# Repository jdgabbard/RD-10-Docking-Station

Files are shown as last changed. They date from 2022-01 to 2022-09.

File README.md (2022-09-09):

# RD-10-Docking-Station
A DIY Docking Station for the Casio MX-10 / MX-15 MSX computers

***REV 2 Board Added to Repository***

***See Build Notes file for special instructions!***

Designed to replace or substitute the KB-10 or KB-15 docking station. Future releases may expand this design. For now, consider it a way to have more than one catridge in your MX-10 or MX-15 at a time.  ***For details, see below.***

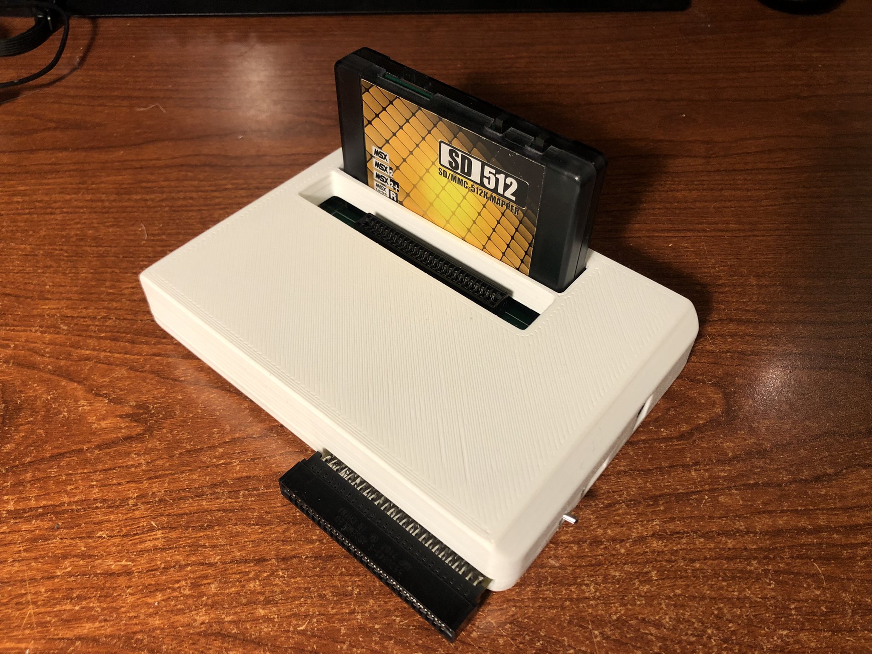
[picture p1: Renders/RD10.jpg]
RD10


Features include:<br><br>
-The ability to directly power the Mx-10 / MX-15 / MX-101 computer from the RD-10 Docking Station.<br>
-Integrated Power Switch for turning on the MX-10.<br>
-Experimental Audio Input Jack (2.5mm) for injecting music into the MSX audio amplifier.<br>
-External Power Connector, allowing powering of Floppy Drives directly from the Docking Station.<br>
-Two Primary Slots<br>
-Construction consisting of off the shelf TTL logic, and current production PLD (ATF22V10).<br>
-Implements +12v/-12v rails, so Audio Cartridges work correctly (MX-10 did not do this on it's one cartridge slot).<br><br>

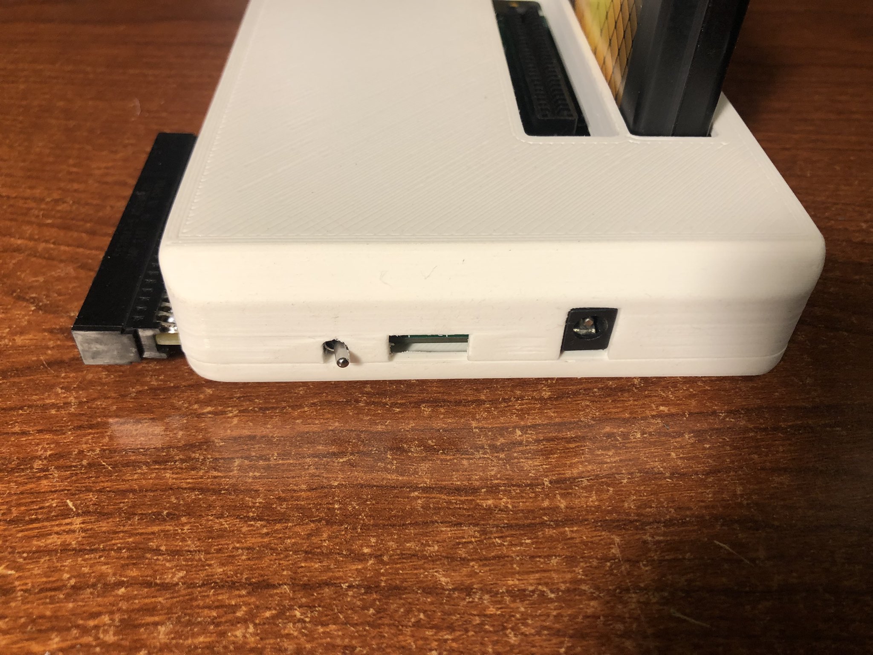
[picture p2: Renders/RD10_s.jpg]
Side

Board

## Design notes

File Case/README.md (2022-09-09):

# RD-10 Printable Enclosure

There are two sets of STL files, a Fusion 360 Archive, and a copy in STEP format.<br>

The STLs are grouped into two categories:  The first being the original exports in millimeters.  The second (resized), which has been resized to 10% of the orignal size.  The second set is for applications where importation assumes the design to be in imperial sizes, and creates a giant version.<br><br>

The Fusion 360 Archive can be used to modify the original design.  You're welcome...<br>

The STEP format can be used to import into other CAD software.  You're welcome...<br>

Build Note: HRA reports M3.5 x 12mm counter sunk screws are a perfect fit.<br>

If you have any issues with these files, please let me know.<br>

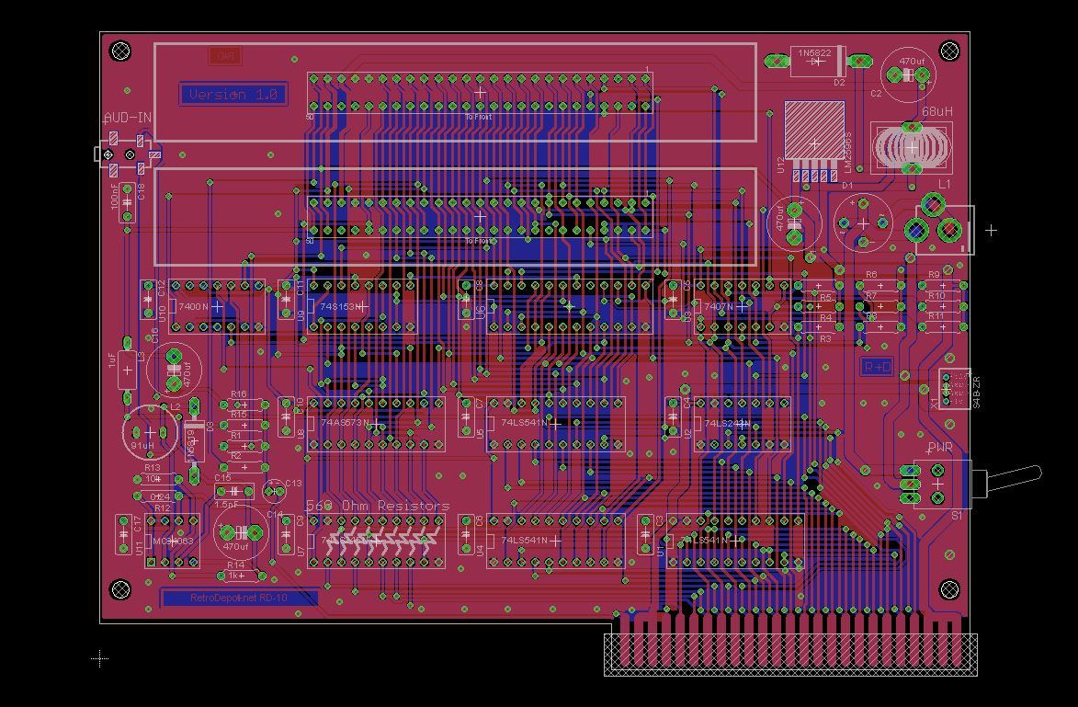
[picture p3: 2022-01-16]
Renders/Board.JPG

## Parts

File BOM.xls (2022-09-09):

Part | Value | Amount | Digikey | Part# | Mouser | Part#
C1,C2,C14,C16 | 470uf | 4 | 732-8743-1-ND | 710-860010575013
C3,C4,C5,C6,C7,C8,C9,C10,C11,C12,C17,C18 | 100nF | 12 | BC1101CT-ND | 594-K104K15X7RF5TH5
C13 | 220uF | 1 | 1189-2237-ND | 232-25YXJ100M5X11
C15 | 1.5nF | 1 | C321C152K3G5TA-ND | 80-C321C152K3G5TA
CONN1,CONN2,CONN3 | Card | Edge | Conn | 3 | A144214-ND | 571-1-5530843-6
D1 | 2W10 | 1 | 2W10G-E4/51 | 625-2W10G-E4
D2 | 1N5822 | 1 | 497-14742-2-ND | 511-1N5822-TR
D3 | 1N5819 | 1 | 497-6610-1-ND | 511-1N581
JP1 | DC | Jack | 1 | CP-002A-ND | 490-PJ-002A
JP2 | Audio | Conn | 1 | 137-MDSMT2BRATRXCT-ND | (unconfirmed) | 502-MDSMT2BRATRX | (unconfirmed)
L1 | 68uH | 1 | 308-2335-ND | (unconfirmed) | 851-RCH8011NP-680L | (unconfirmed)
L2 | 91uH | (100uH) | 1 | 399-20012-ND | (unconfirmed) | 80-SBCP-47HY101B | (unconfirmed)
L3 | 1uF | 1 | 495-5547-2-ND | (unconfirmed) | 871-B78108S1102K | (unconfirmed)
R1,R2,R15,R16 | 330R | 4 | MFR-25FBF52-330R-ND | 603-MFR-25FBF52-330R
R3,R4,R5,R6,R7,R8,R9,R10,R11 | 4.7k | 9 | 4.7KQBK-ND | 603-CFR-25JB-52-4K7
R12 | 0.24R | 1 | A138235CT-ND | 279-RR01JR24TB
R13 | 10k | 1 | 10KQBK-ND | 603-CFR-25JB-52-10K
R14 | 1k | 1 | 1.0KQBK-ND | 603-CFR-25JB-1K0
S1 | Power | Switch | 1 | EG5420-ND | 612-200MSP1T3B4M6RE
U1,U4,U5 | 74F541N | 3 | 296-3594-5-ND | 595-SN74F541N
U2 | 74ALS243N | (HCT) | 1 | 296-2145-5-ND | 595-CD74HCT243E
U3 | 74LS07N | 1 | 296-14878-5-ND | 595-SN74LS07N
U6 | 22V10 | 1 | 2156-ATF22V10CQ-15PC-AT-ND | 556-AF22V10C7PX
U7 | -See | Note- | 8 | CF14JT560RCT-ND | 603-CFR-25JB-52-560R
U8 | 74LS573N | (HCT) | 1 | 296-2128-5-ND | 595-CD74HCT573E
U9 | 74F153N | 1 | 296-3555-5-ND | 595-SN74F153N
U10 | 74F00N | 1 | 296-3539-5-ND | 595-SN74F00N
U11 | MC34063 | 1 | 497-4280-5-ND | 511-MC34063ECN
U12 | LM2596S | 1 | LM2596S-5.0/NOPB-ND | 926-LM2596S-5.0/NOPB
X1 | Floppy | Power | Conn | 1 | A144577-ND | 571-3-641207-4 | Not | currently | used, | wrong | footprint.
Notes:
U7 | should be fitted with 560ohm resistors as noted on PCB
R13 in Rev2 | should be 10k potentiometer

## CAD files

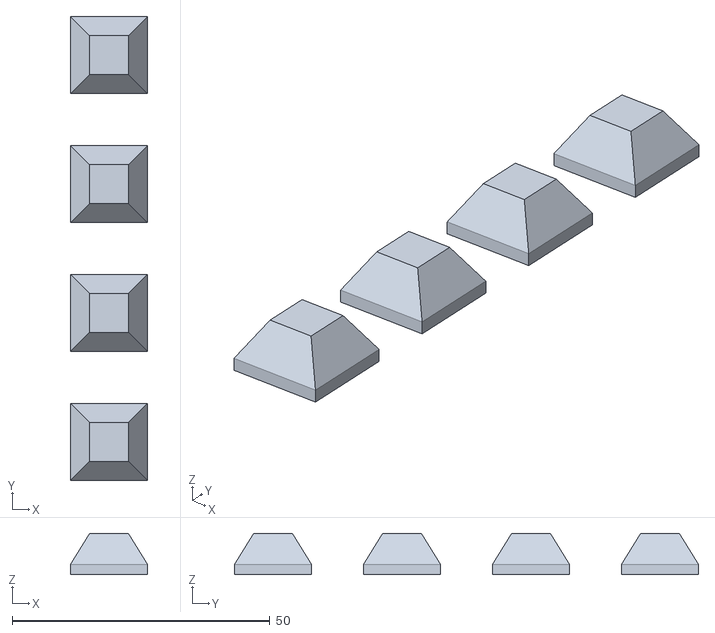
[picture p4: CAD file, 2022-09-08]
Case/Feet_resized.stl
14.9 x 89.9 x 8.00

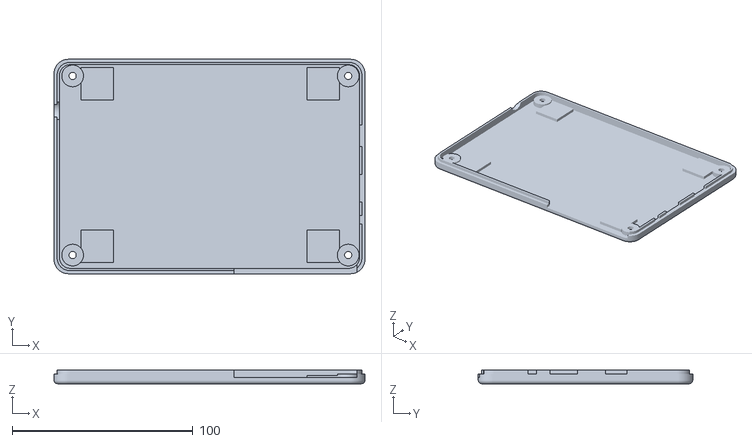
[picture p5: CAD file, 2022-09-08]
Case/Base_resized.stl
172.0 x 118.6 x 7.50

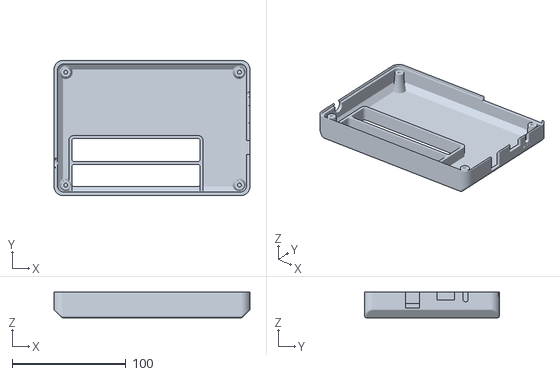
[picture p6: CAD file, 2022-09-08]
Case/Top_resized.stl
172.0 x 118.7 x 22.5

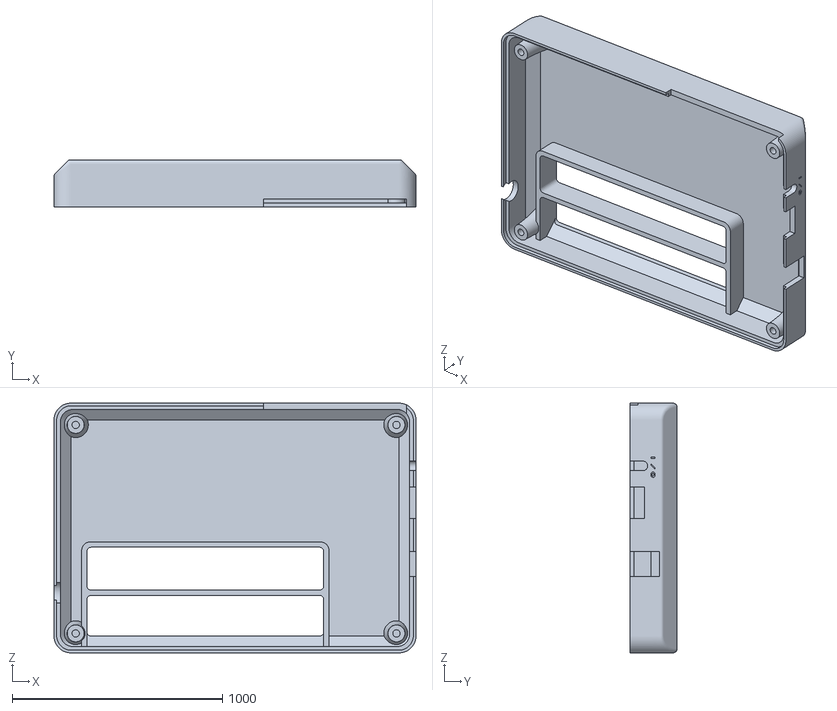
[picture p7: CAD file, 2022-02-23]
Case/Top.stl
1720.0 x 225.0 x 1186.5

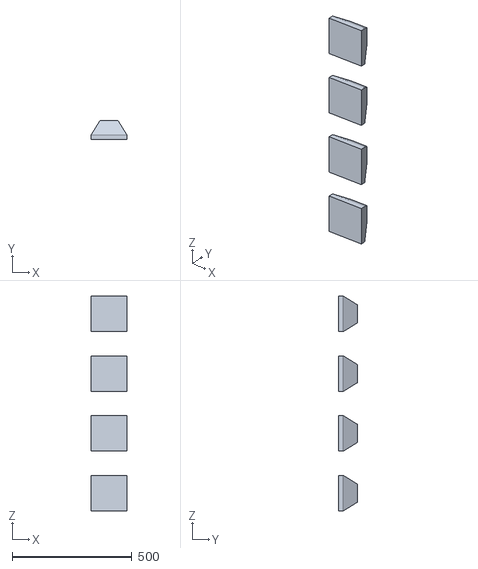
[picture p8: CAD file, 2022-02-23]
Case/Feet.stl
149.3 x 80.0 x 899.3

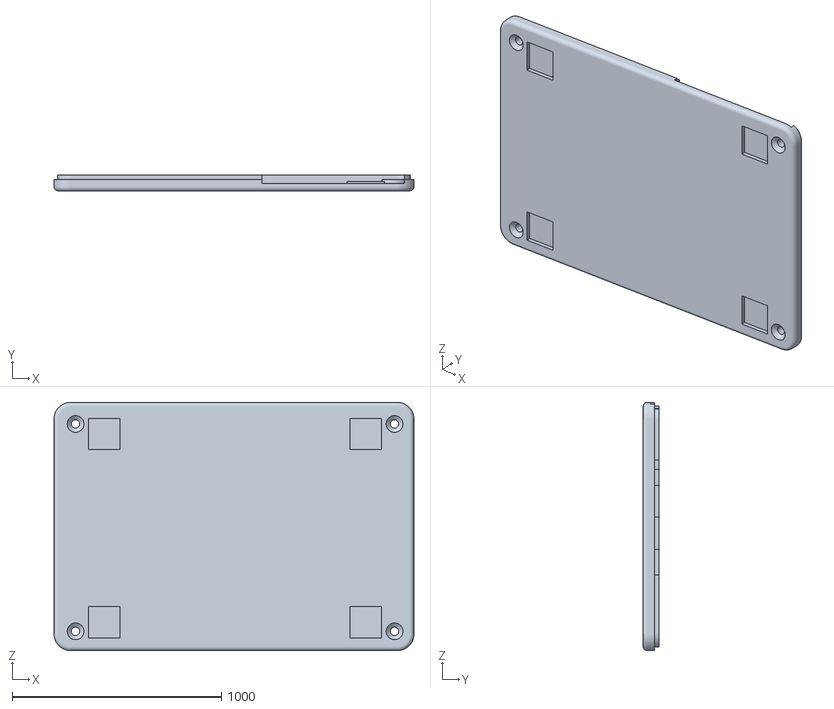
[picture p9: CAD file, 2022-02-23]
Case/Base.stl
1720.0 x 75.0 x 1186.5

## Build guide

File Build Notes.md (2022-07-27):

# Build Notes

***I would suggest fitting U6 and U7 with Sockets.***  U6 is for the 22V10 PLD, and should be socketed so updated JEDECs can be programmed.  I suggest socketing U7 to allow switching between a Bus Transceiver and Resistor.  Once the cause of the Bus Transceiver's incorrect operation is determined, a modified JEDEC, BOM or Board design will be released so that a Transceiver can be used.

***Until then use resistors in place of U7!***

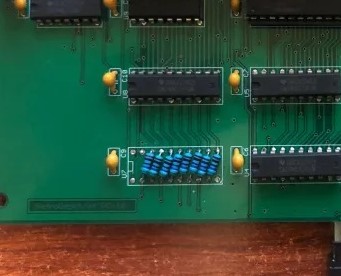
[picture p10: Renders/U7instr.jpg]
U7


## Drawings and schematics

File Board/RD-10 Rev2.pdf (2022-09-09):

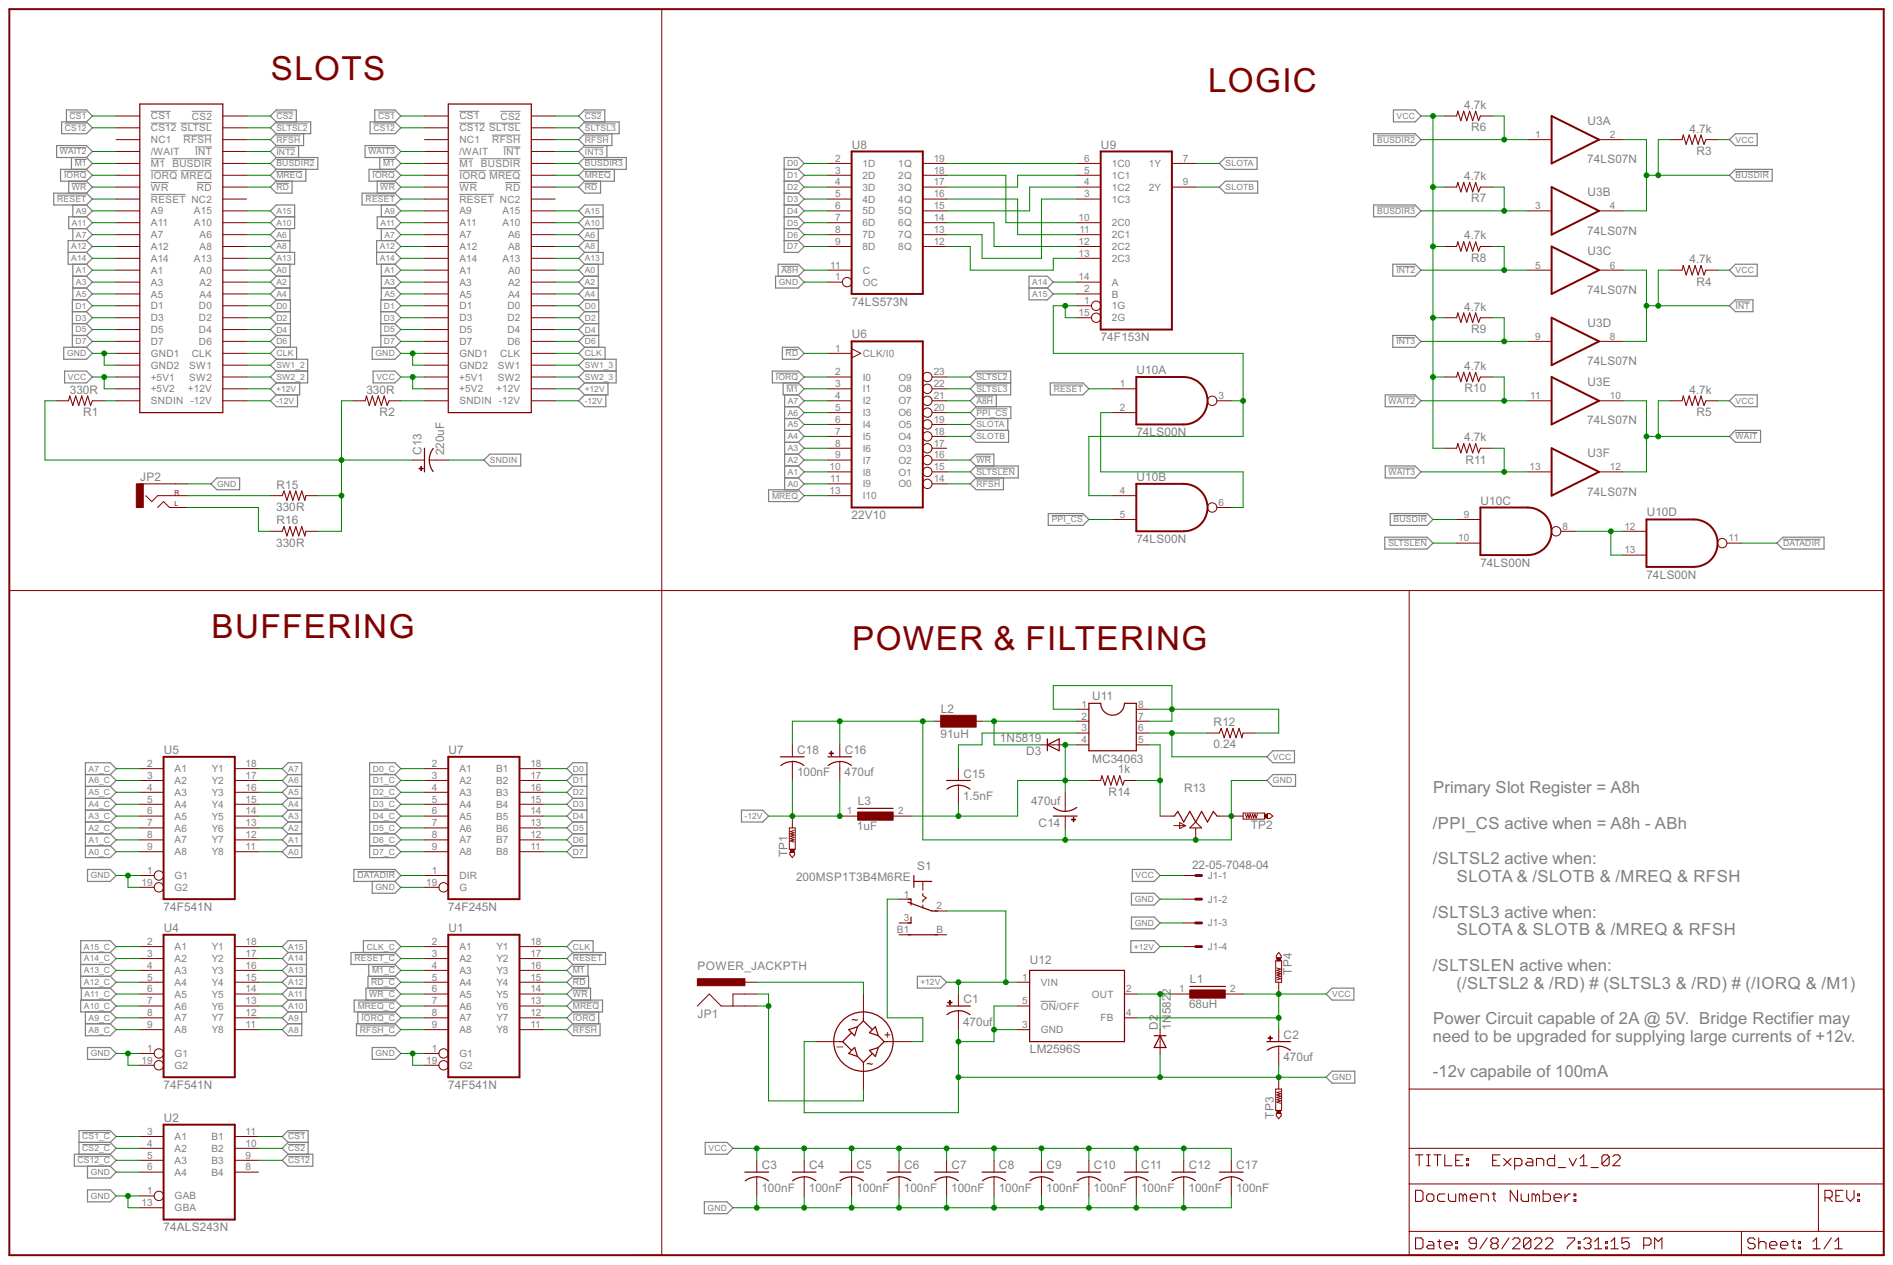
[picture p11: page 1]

GND | 2 A15

/SLTSL2 active when: SLOTA & /SLOTB & /MREQ & RFSH

/SLTSL3 active when: SLOTA & SLOTB & /MREQ & RFSH

/SLTSLEN active when: (/SLTSL2 & /RD) # (SLTSL3 & /RD) # (/IORQ & /M1)

Power Circuit capable of 2A @ 5V. Bridge Rectifier may need to be upgraded for supplying large currents of +12v. -12v capabile of 100mA

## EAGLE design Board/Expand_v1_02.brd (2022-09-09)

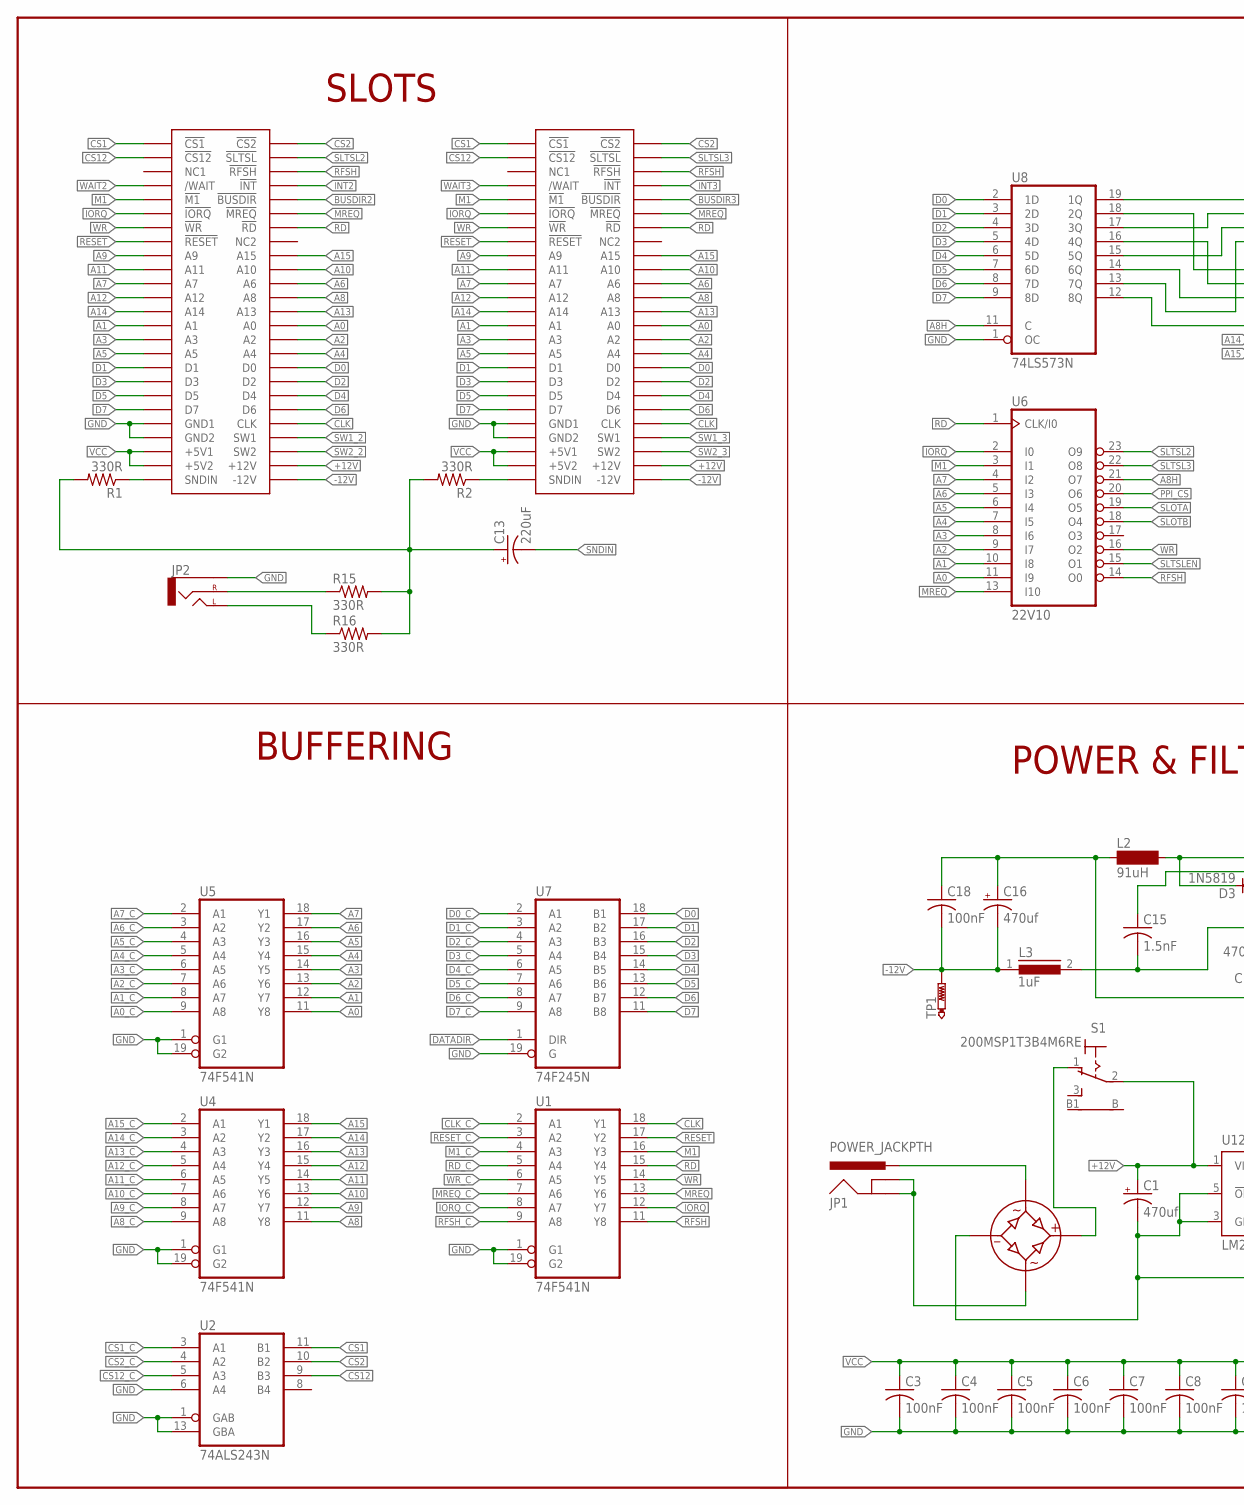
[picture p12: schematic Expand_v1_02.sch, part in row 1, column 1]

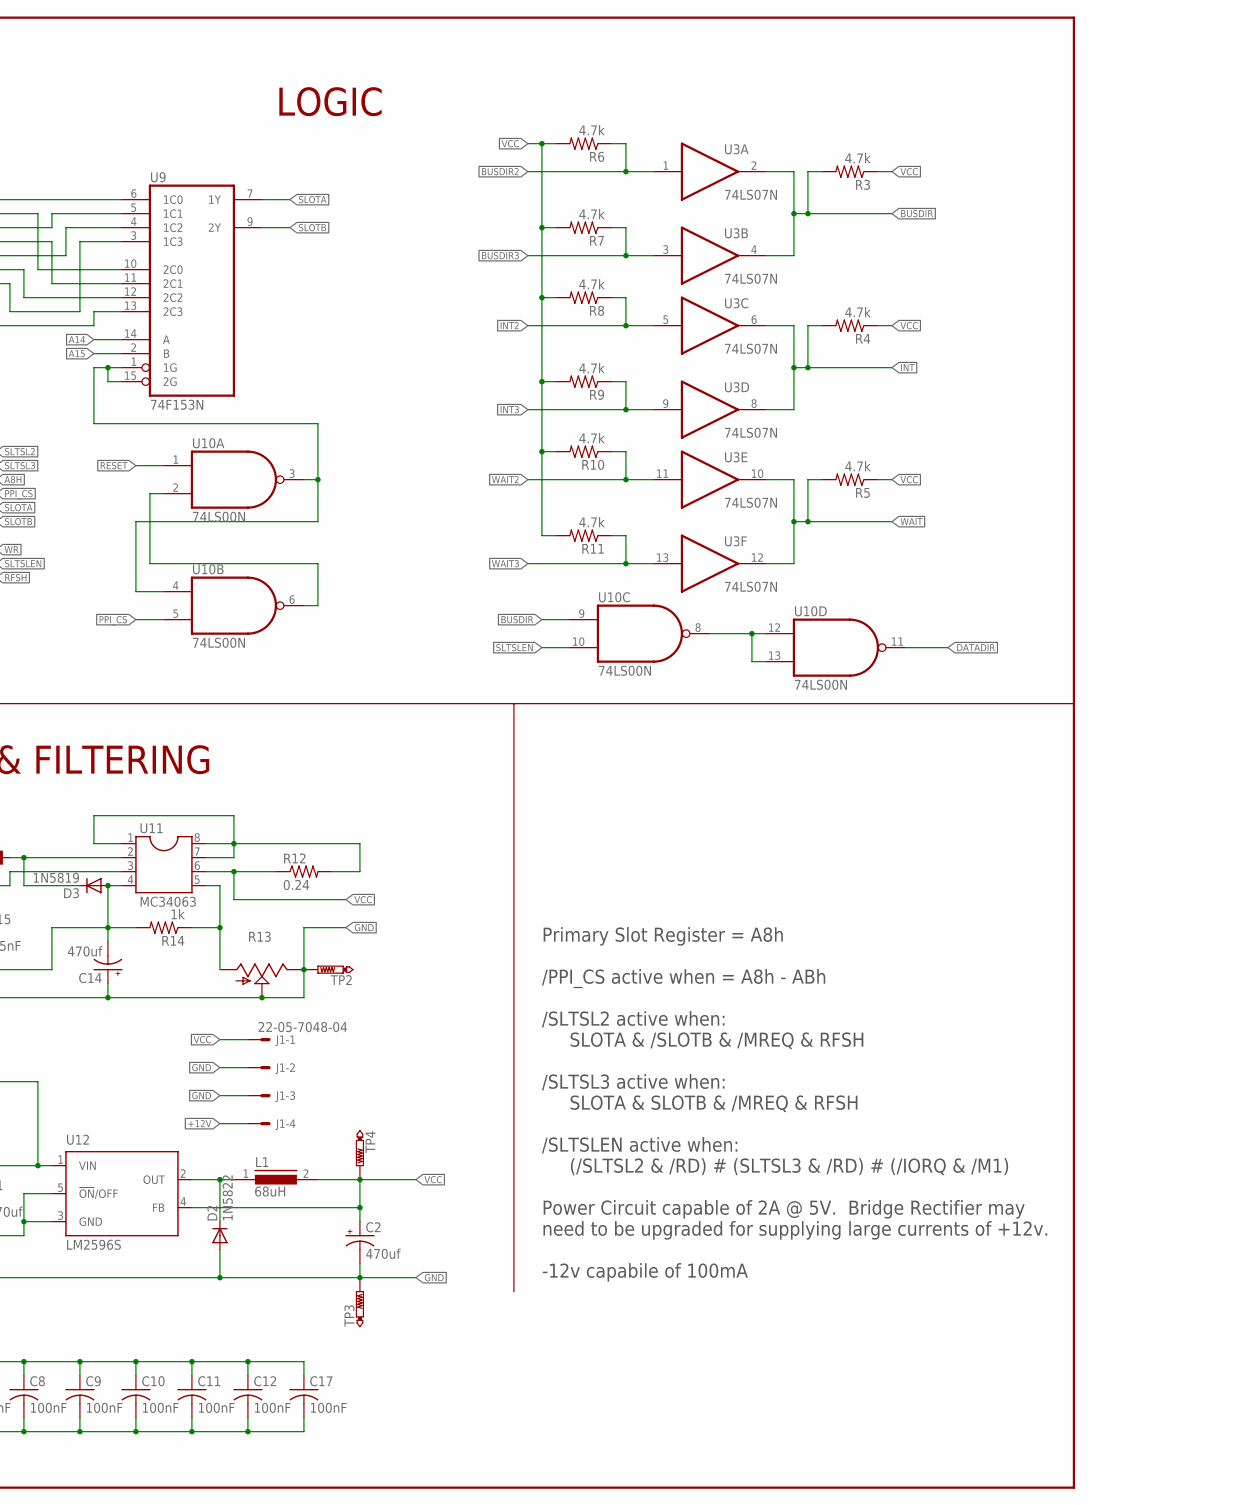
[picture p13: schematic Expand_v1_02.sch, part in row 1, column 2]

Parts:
C1, C2, C14, C16: 470uf; E5-10,5
C3, C4, C5, C6, C7, C8, C9, C10, C11, C12, C17, C18: 100nF; C050-030X075
C13: 220uF; E2-4
C15: 1.5nF; C050-030X075
CONN2, CONN3: MSX_CART_SLOT; CART_SLOT
D1: 2W10
D2: 1N5822; DO201-15
D3: 1N5819; DO15-12
J1: 22-05-7048-04; 7395-04
JP1: POWER_JACKPTH; POWER_JACK_PTH
JP2: AUDIO-JACK1:1; STEREOJACK2.5MM
L1: 68uH; A26GFC
L2: 91uH; BS11
L3: 1uF; MCC10
R1, R2, R15, R16: 330R; 0207/7
R3, R4, R5, R6, R7, R8, R9, R10, R11: 4.7k; 0207/7
R12: 0.24; 0207/10
R13: TRIM_US-RJ9W; RJ9W
R14: 1k; 0207/7
S1: 200MSP1T3B4M6RE; 9070-1W
TP1, TP2, TP3, TP4: PTR1B2,54; B2,54
U1, U4, U5: 74F541N; DIL20
U2: 74ALS243N; DIL14
U3: 74LS07N; DIL14
U6: 22V10; DIL24-3
U7: 74F245N; DIL20
U8: 74LS573N; DIL20
U9: 74F153N; DIL16
U10: 74LS00N; DIL14
U11: MC34063; DIL08
U12: LM2596S; TO263-5

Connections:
!A8H: U6.21 (O7), U8.11 (C)
!BUSDIR: R3.2, U3.2 (O), U3.4 (O), U10.9 (I0)
!BUSDIR2: CONN2.P$10 (!BUSDIR), R6.1, U3.1 (I)
!BUSDIR3: CONN3.P$10 (!BUSDIR), R7.1, U3.3 (I)
!CS1: CONN2.P$1 (!CS1), CONN3.P$1 (!CS1), U2.11 (B1)
!CS1_C: U2.3 (A1)
!CS2: CONN2.P$2 (!CS2), CONN3.P$2 (!CS2), U2.10 (B2)
!CS2_C: U2.4 (A2)
!CS12: CONN2.P$3 (!CS12), CONN3.P$3 (!CS12), U2.9 (B3)
!CS12_C: U2.5 (A3)
!DATADIR: U7.1 (DIR), U10.11 (O)
!INT: R4.2, U3.6 (O), U3.8 (O)
!INT2: CONN2.P$8 (!INT), R8.1, U3.5 (I)
!INT3: CONN3.P$8 (!INT), R9.1, U3.9 (I)
!IORQ: CONN2.P$11 (!IORQ), CONN3.P$11 (!IORQ), U1.12 (Y7), U6.2 (I0)
!IORQ_C: U1.8 (A7)
!M1: CONN2.P$9 (!M1), CONN3.P$9 (!M1), U1.16 (Y3), U6.3 (I1)
!M1_C: U1.4 (A3)
!MREQ: CONN2.P$12 (!MREQ), CONN3.P$12 (!MREQ), U1.13 (Y6), U6.13 (I10)
!MREQ_C: U1.7 (A6)
!PPI_CS: U6.20 (O6), U10.5 (I1)
!RD: CONN2.P$14 (!RD), CONN3.P$14 (!RD), U1.15 (Y4), U6.1 (CLK/I0)
!RD_C: U1.5 (A4)
!RESET: CONN2.P$15 (!RESET), CONN3.P$15 (!RESET), U1.17 (Y2), U10.1 (I0)
!RESET_C: U1.3 (A2)
!RFSH: CONN2.P$6 (!RFSH), CONN3.P$6 (!RFSH), U1.11 (Y8), U6.14 (O0)
!RFSH_C: U1.9 (A8)
!SLTSL2: CONN2.P$4 (!SLTSL), U6.23 (O9)
!SLTSL3: CONN3.P$4 (!SLTSL), U6.22 (O8)
!SLTSLEN: U6.15 (O1), U10.10 (I1)
!WAIT: R5.2, U3.10 (O), U3.12 (O)
!WAIT2: CONN2.P$7 (/WAIT), R10.1, U3.11 (I)
!WAIT3: CONN3.P$7 (/WAIT), R11.1, U3.13 (I)
!WR: CONN2.P$13 (!WR), CONN3.P$13 (!WR), U1.14 (Y5), U6.16 (O2)
!WR_C: U1.6 (A5)
+12V: C1.+, CONN2.P$48 (+12V), CONN3.P$48 (+12V), J1.4, S1.2, U12.1 (VIN)
-12V: C16.-, C18.2, CONN2.P$50 (-12V), CONN3.P$50 (-12V), L3.1, TP1.TP
A0: CONN2.P$28 (A0), CONN3.P$28 (A0), U5.11 (Y8), U6.11 (I9)
A0_C: U5.9 (A8)
A1: CONN2.P$27 (A1), CONN3.P$27 (A1), U5.12 (Y7), U6.10 (I8)
A1_C: U5.8 (A7)
A2: CONN2.P$30 (A2), CONN3.P$30 (A2), U5.13 (Y6), U6.9 (I7)
A2_C: U5.7 (A6)
A3: CONN2.P$29 (A3), CONN3.P$29 (A3), U5.14 (Y5), U6.8 (I6)
A3_C: U5.6 (A5)
A4: CONN2.P$32 (A4), CONN3.P$32 (A4), U5.15 (Y4), U6.7 (I5)
A4_C: U5.5 (A4)
A5: CONN2.P$31 (A5), CONN3.P$31 (A5), U5.16 (Y3), U6.6 (I4)
A5_C: U5.4 (A3)
A6: CONN2.P$22 (A6), CONN3.P$22 (A6), U5.17 (Y2), U6.5 (I3)
A6_C: U5.3 (A2)
A7: CONN2.P$21 (A7), CONN3.P$21 (A7), U5.18 (Y1), U6.4 (I2)
A7_C: U5.2 (A1)
A8: CONN2.P$24 (A8), CONN3.P$24 (A8), U4.11 (Y8)
A8_C: U4.9 (A8)
A9: CONN2.P$17 (A9), CONN3.P$17 (A9), U4.12 (Y7)
A9_C: U4.8 (A7)
A10: CONN2.P$20 (A10), CONN3.P$20 (A10), U4.13 (Y6)
A10_C: U4.7 (A6)
A11: CONN2.P$19 (A11), CONN3.P$19 (A11), U4.14 (Y5)
A11_C: U4.6 (A5)
A12: CONN2.P$23 (A12), CONN3.P$23 (A12), U4.15 (Y4)
A12_C: U4.5 (A4)
A13: CONN2.P$26 (A13), CONN3.P$26 (A13), U4.16 (Y3)
A13_C: U4.4 (A3)
A14: CONN2.P$25 (A14), CONN3.P$25 (A14), U4.17 (Y2), U9.14 (A)
A14_C: U4.3 (A2)
A15: CONN2.P$18 (A15), CONN3.P$18 (A15), U4.18 (Y1), U9.2 (B)
A15_C: U4.2 (A1)
CLK: CONN2.P$42 (CLK), CONN3.P$42 (CLK), U1.18 (Y1)
CLK_C: U1.2 (A1)
D0: CONN2.P$34 (D0), CONN3.P$34 (D0), U7.18 (B1), U8.2 (1D)
D0_C: U7.2 (A1)
D1: CONN2.P$33 (D1), CONN3.P$33 (D1), U7.17 (B2), U8.3 (2D)
D1_C: U7.3 (A2)
D2: CONN2.P$36 (D2), CONN3.P$36 (D2), U7.16 (B3), U8.4 (3D)
D2_C: U7.4 (A3)
D3: CONN2.P$35 (D3), CONN3.P$35 (D3), U7.15 (B4), U8.5 (4D)
D3_C: U7.5 (A4)
D4: CONN2.P$38 (D4), CONN3.P$38 (D4), U7.14 (B5), U8.6 (5D)
D4_C: U7.6 (A5)
D5: CONN2.P$37 (D5), CONN3.P$37 (D5), U7.13 (B6), U8.7 (6D)
D5_C: U7.7 (A6)
D6: CONN2.P$40 (D6), CONN3.P$40 (D6), U7.12 (B7), U8.8 (7D)
D6_C: U7.8 (A7)
D7: CONN2.P$39 (D7), CONN3.P$39 (D7), U7.11 (B8), U8.9 (8D)
D7_C: U7.9 (A8)
GND: C1.-, C2.-, C3.2, C4.2, C5.2, C6.2, C7.2, C8.2, C9.2, C10.2, C11.2, C12.2, C14.+, C16.+, C17.2, C18.1, CONN2.P$41 (GND1), CONN2.P$43 (GND2), CONN3.P$41 (GND1), CONN3.P$43 (GND2), D1.P$4, D2.A, J1.2, J1.3, JP2.5 (SLEEVE), L2.1, R13.E, R13.S, TP2.TP, TP3.TP, U1.1 (G1), U1.10 (GND), U1.19 (G2), U2.1 (GAB), U2.6 (A4), U2.7 (GND), U2.13 (GBA), U3.7 (GND), U4.1 (G1), U4.10 (GND), U4.19 (G2), U5.1 (G1), U5.10 (GND), U5.19 (G2), U6.12 (GND), U7.10 (GND), U7.19 (G), U8.1 (OC), U8.10 (GND), U9.8 (GND), U10.7 (GND), U12.3 (GND), U12.5 (!ON!/OFF)
unnamed: CONN3.P$49 (SNDIN), R2.1
unnamed: CONN2.P$49 (SNDIN), R1.1
unnamed: U8.19 (1Q), U9.6 (1C0)
unnamed: C13.+, R1.2, R2.2, R15.2, R16.2
unnamed: U8.18 (2Q), U9.10 (2C0)
unnamed: U8.17 (3Q), U9.5 (1C1)
unnamed: U8.16 (4Q), U9.11 (2C1)
unnamed: U8.15 (5Q), U9.4 (1C2)
unnamed: U8.14 (6Q), U9.12 (2C2)
unnamed: U8.13 (7Q), U9.3 (1C3)
unnamed: U8.12 (8Q), U9.13 (2C3)
unnamed: U10.2 (I1), U10.6 (O)
unnamed: U9.1 (1G), U9.15 (2G), U10.3 (O), U10.4 (I0)
unnamed: U10.8 (O), U10.12 (I0), U10.13 (I1)
unnamed: D1.P$2, S1.1 (O)
unnamed: R12.2, U11.1, U11.7, U11.8
unnamed: JP2.4 (RIGHT), R15.1
unnamed: R13.A, R14.1, U11.5
unnamed: D1.P$1, JP1.PWR
unnamed: D1.P$3, JP1.GND, JP1.GNDBREAK
unnamed: C14.-, C15.2, D3.A, L3.2, R14.2, U11.4
unnamed: C15.1, U11.3
unnamed: D3.C, L2.2, U11.2
unnamed: JP2.1 (LEFT), R16.1
unnamed: D2.C, L1.1, U12.2 (OUT)
SLOTA: U6.19 (O5), U9.7 (1Y)
SLOTB: U6.18 (O4), U9.9 (2Y)
SNDIN: C13.-
SW1_2: CONN2.P$44 (SW1)
SW1_3: CONN3.P$44 (SW1)
SW2_2: CONN2.P$46 (SW2)
SW2_3: CONN3.P$46 (SW2)
VCC: C2.+, C3.1, C4.1, C5.1, C6.1, C7.1, C8.1, C9.1, C10.1, C11.1, C12.1, C17.1, CONN2.P$45 (+5V1), CONN2.P$47 (+5V2), CONN3.P$45 (+5V1), CONN3.P$47 (+5V2), J1.1, L1.2, R3.1, R4.1, R5.1, R6.2, R7.2, R8.2, R9.2, R10.2, R11.2, R12.1, TP4.TP, U1.20 (VCC), U2.14 (VCC), U3.14 (VCC), U4.20 (VCC), U5.20 (VCC), U6.24 (VCC), U7.20 (VCC), U8.20 (VCC), U9.16 (VCC), U10.14 (VCC), U11.6, U12.4 (FB)

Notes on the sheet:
SLOTS
LOGIC
BUFFERING
POWER & FILTERING
Primary Slot Register = A8h /PPI_CS active when = A8h - ABh /SLTSL2 active when: SLOTA & /SLOTB & /MREQ & RFSH /SLTSL3 active when: SLOTA & SLOTB & /MREQ & RFSH /SLTSLEN active when: (/SLTSL2 & /RD) # (SLTSL3 & /RD) # (/IORQ & /M1) Power Circuit capable of 2A @ 5V. Bridge Rectifier may need to be u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

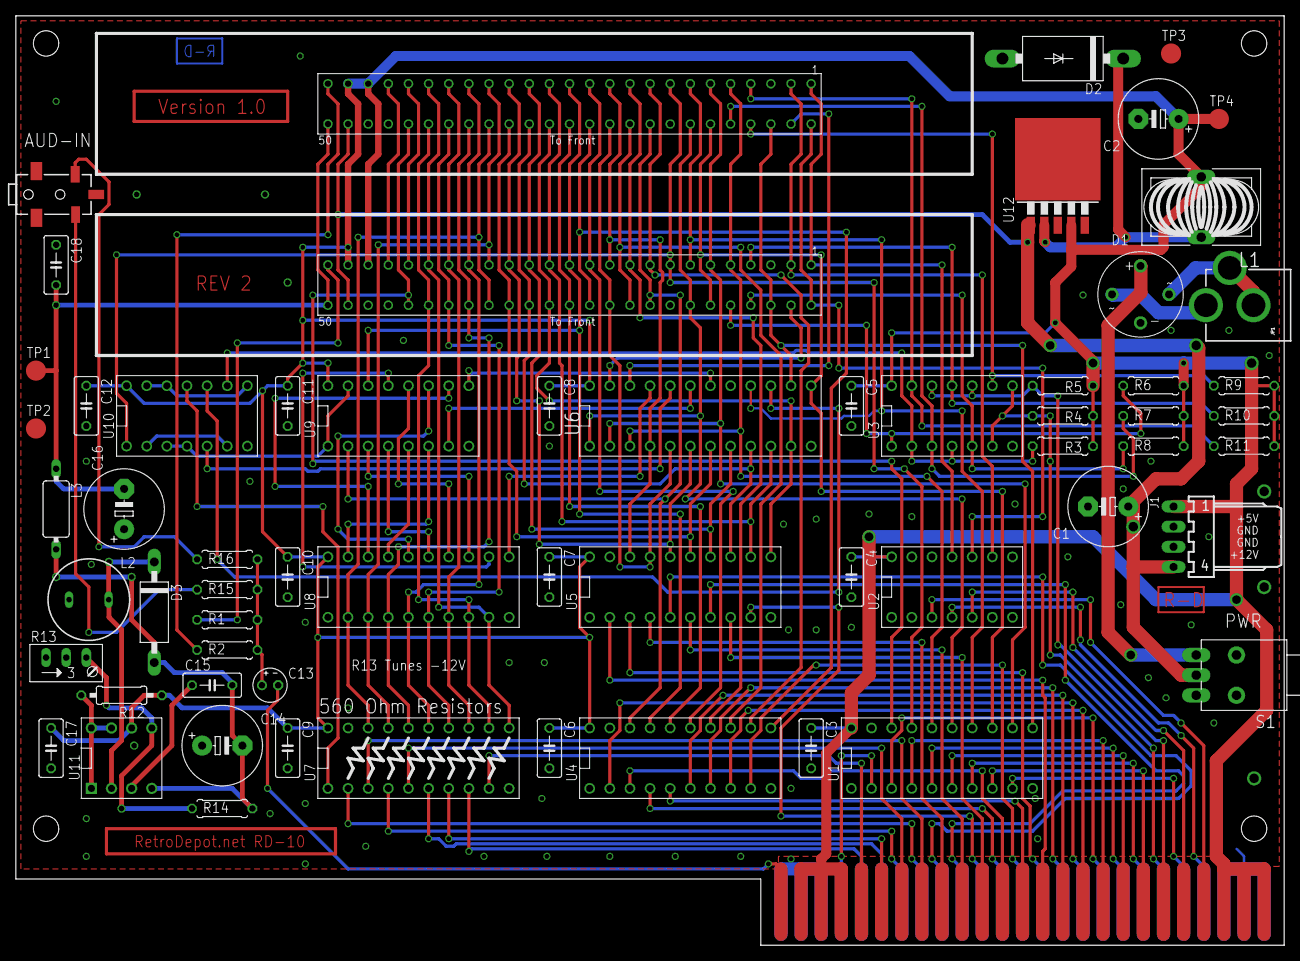
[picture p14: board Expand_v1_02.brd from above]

Board: 2 copper layers, 160.0 x 117.2 mm, 62 parts (0 on the bottom side), 81 nets.

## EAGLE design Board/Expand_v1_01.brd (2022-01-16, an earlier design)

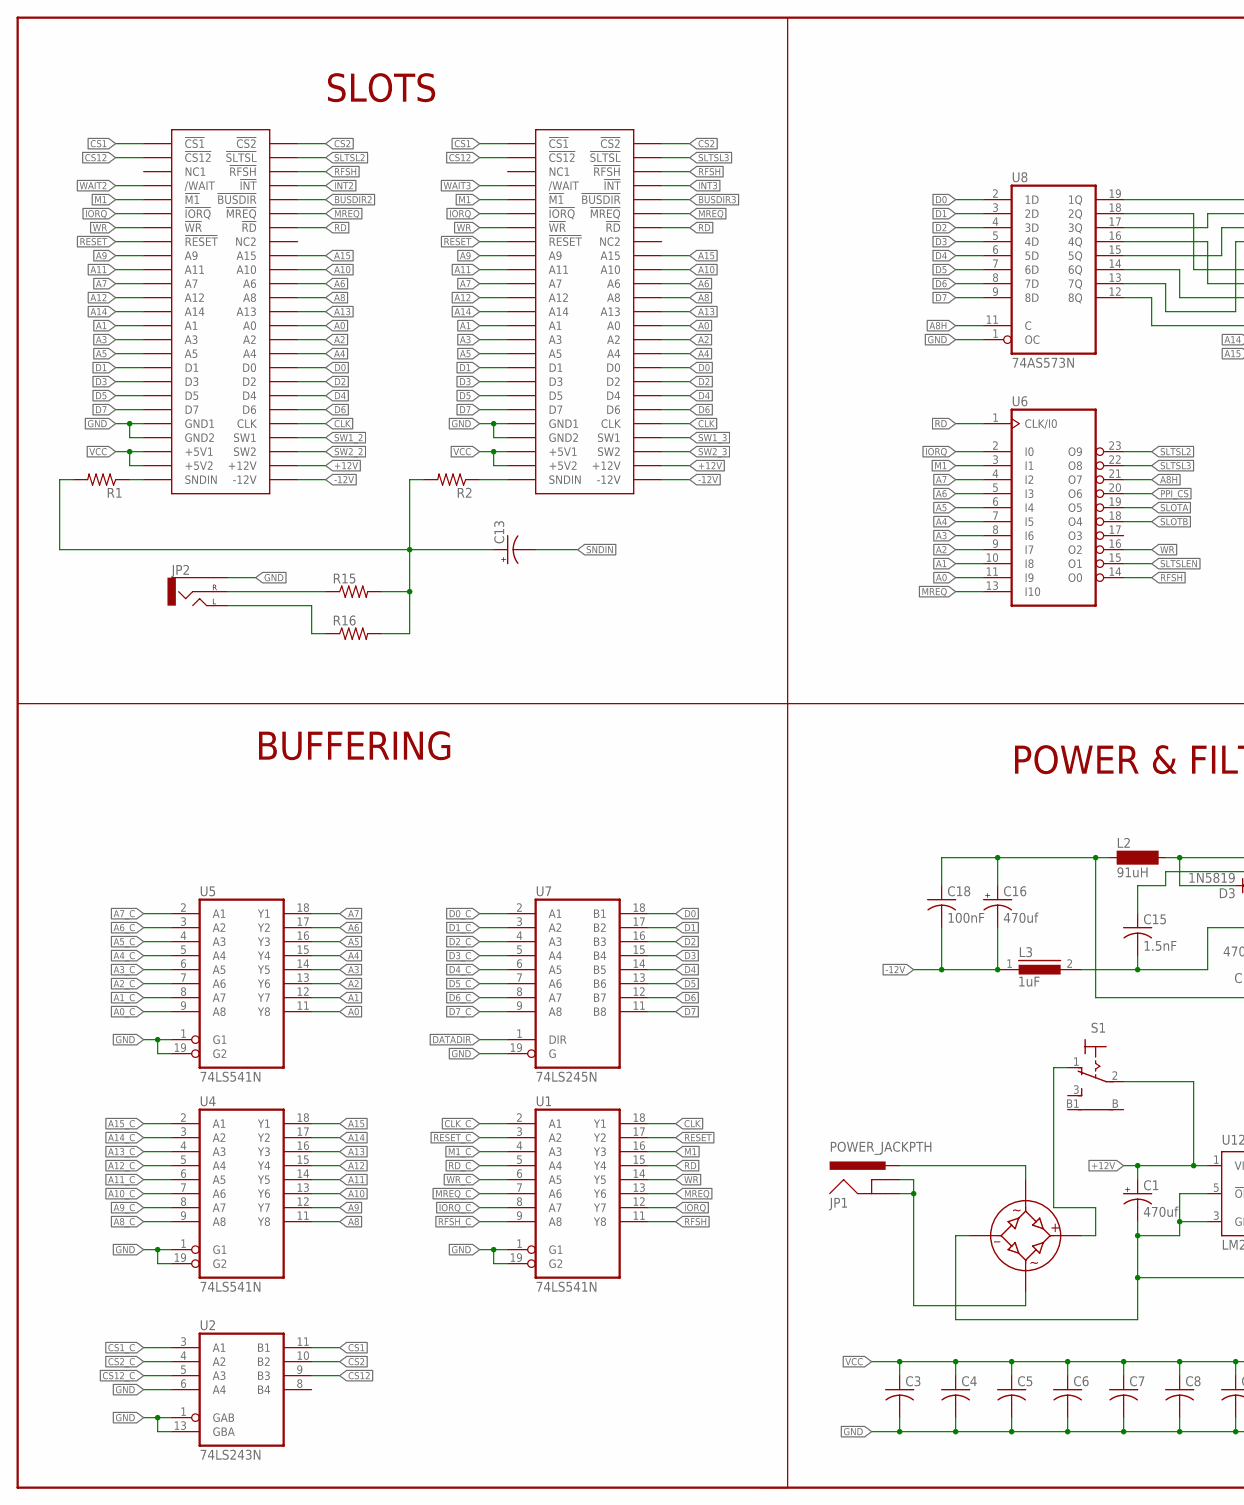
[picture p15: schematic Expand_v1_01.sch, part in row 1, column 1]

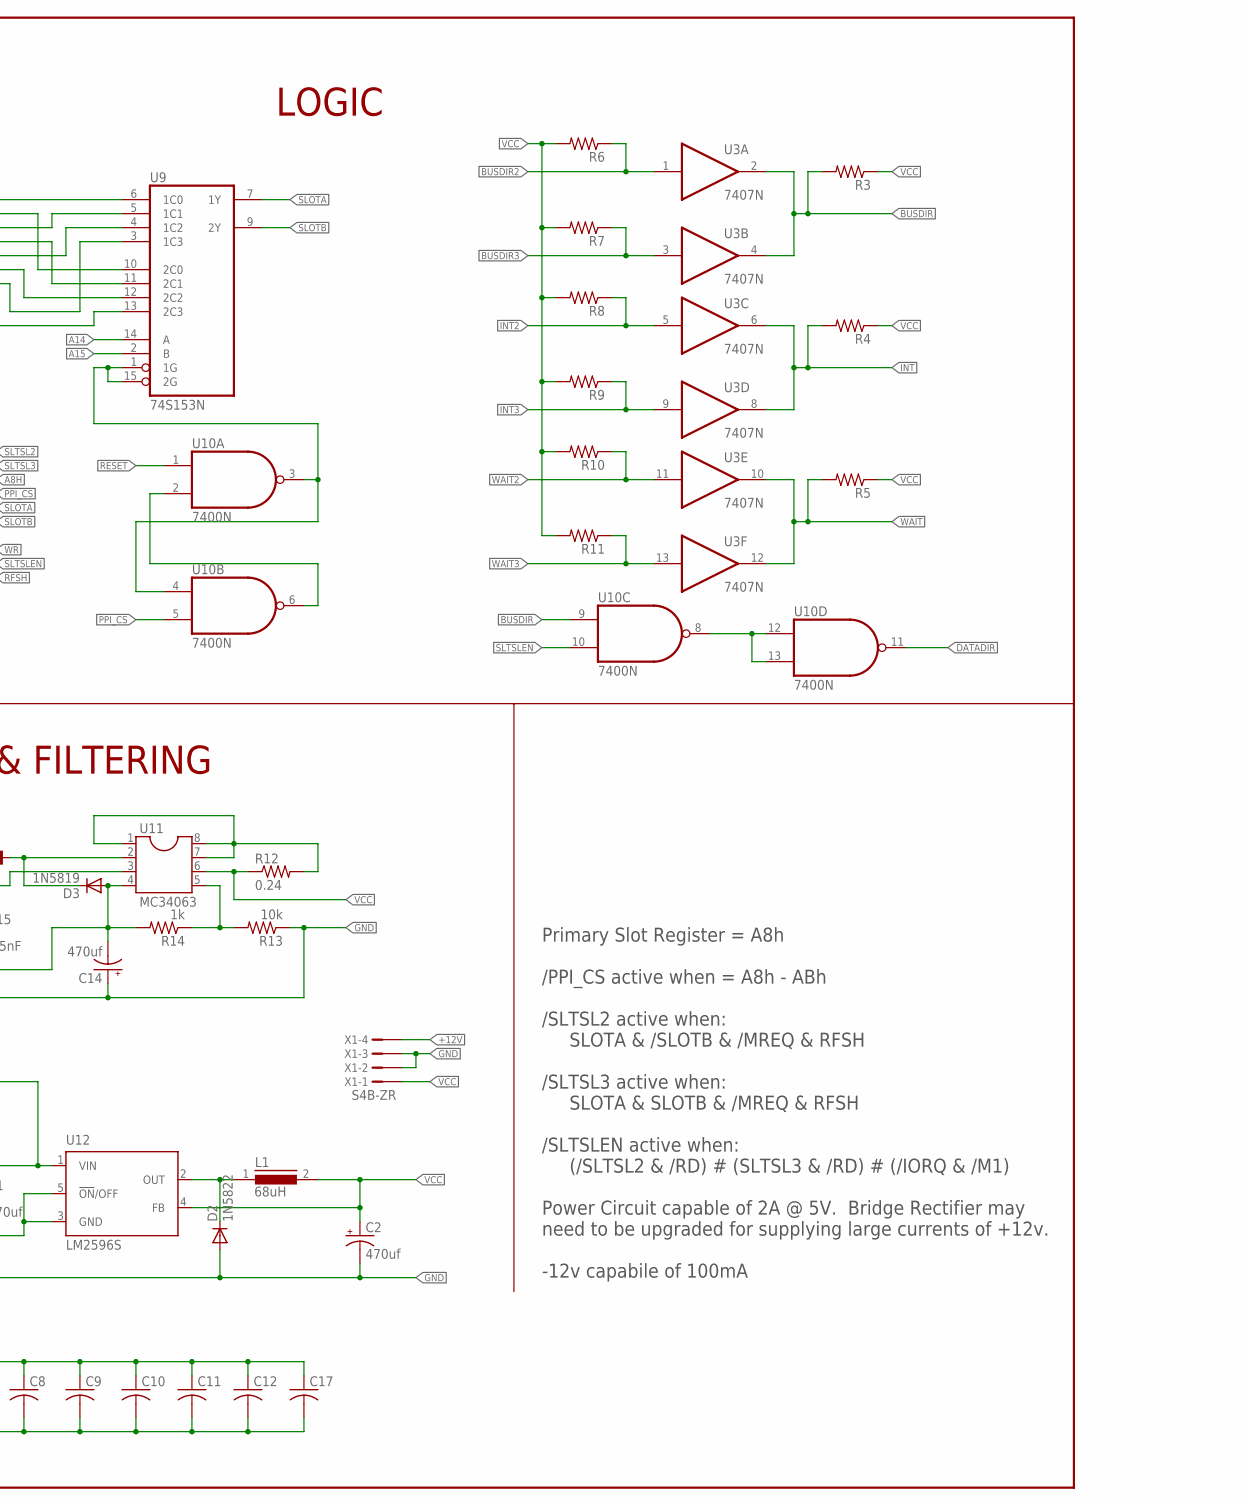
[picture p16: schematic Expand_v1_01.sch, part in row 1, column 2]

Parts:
C1, C2, C14, C16: 470uf; E5-10,5
C3, C4, C5, C6, C7, C8, C9, C10, C11, C12, C17: C-US050-030X075; C050-030X075
C13: CPOL-USE2-4; E2-4
C15: 1.5nF; C050-030X075
C18: 100nF; C050-030X075
D1: 2W10
D2: 1N5822; DO201-15
D3: 1N5819; DO15-12
JP1: POWER_JACKPTH; POWER_JACK_PTH
JP2: AUDIO-JACK1:1; STEREOJACK2.5MM
L1: 68uH; A26GFC
L2: 91uH; BS11
L3: 1uF; MCC10
R1, R2, R3, R4, R5, R6, R7, R8, R9, R10, R11, R15, R16: R-US_0207/7; 0207/7
R12: 0.24; 0207/7
R13: 10k; 0207/7
R14: 1k; 0207/7
S1: 9070-1W
U1, U4, U5: 74LS541N; DIL20
U2: 74LS243N; DIL14
U3: 7407N; DIL14
U6: 22V10; DIL24-3
U7: 74LS245N; DIL20
U8: 74AS573N; DIL20
U9: 74S153N; DIL16
U10: 7400N; DIL14
U11: MC34063; DIL08
U12: LM2596S; TO263-5
U$1, U$2: MSX_CART_SLOT; CART_SLOT
X1: S4B-ZR

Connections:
!A8H: U6.21 (O7), U8.11 (C)
!BUSDIR: R3.2, U3.2 (O), U3.4 (O), U10.9 (I0)
!BUSDIR2: R6.1, U3.1 (I), U$1.P$10 (!BUSDIR)
!BUSDIR3: R7.1, U3.3 (I), U$2.P$10 (!BUSDIR)
!CS1: U2.11 (B1), U$1.P$1 (!CS1), U$2.P$1 (!CS1)
!CS1_C: U2.3 (A1)
!CS2: U2.10 (B2), U$1.P$2 (!CS2), U$2.P$2 (!CS2)
!CS2_C: U2.4 (A2)
!CS12: U2.9 (B3), U$1.P$3 (!CS12), U$2.P$3 (!CS12)
!CS12_C: U2.5 (A3)
!DATADIR: U7.1 (DIR), U10.11 (O)
!INT: R4.2, U3.6 (O), U3.8 (O)
!INT2: R8.1, U3.5 (I), U$1.P$8 (!INT)
!INT3: R9.1, U3.9 (I), U$2.P$8 (!INT)
!IORQ: U1.12 (Y7), U6.2 (I0), U$1.P$11 (!IORQ), U$2.P$11 (!IORQ)
!IORQ_C: U1.8 (A7)
!M1: U1.16 (Y3), U6.3 (I1), U$1.P$9 (!M1), U$2.P$9 (!M1)
!M1_C: U1.4 (A3)
!MREQ: U1.13 (Y6), U6.13 (I10), U$1.P$12 (!MREQ), U$2.P$12 (!MREQ)
!MREQ_C: U1.7 (A6)
!PPI_CS: U6.20 (O6), U10.5 (I1)
!RD: U1.15 (Y4), U6.1 (CLK/I0), U$1.P$14 (!RD), U$2.P$14 (!RD)
!RD_C: U1.5 (A4)
!RESET: U1.17 (Y2), U10.1 (I0), U$1.P$15 (!RESET), U$2.P$15 (!RESET)
!RESET_C: U1.3 (A2)
!RFSH: U1.11 (Y8), U6.14 (O0), U$1.P$6 (!RFSH), U$2.P$6 (!RFSH)
!RFSH_C: U1.9 (A8)
!SLTSL2: U6.23 (O9), U$1.P$4 (!SLTSL)
!SLTSL3: U6.22 (O8), U$2.P$4 (!SLTSL)
!SLTSLEN: U6.15 (O1), U10.10 (I1)
!WAIT: R5.2, U3.10 (O), U3.12 (O)
!WAIT2: R10.1, U3.11 (I), U$1.P$7 (/WAIT)
!WAIT3: R11.1, U3.13 (I), U$2.P$7 (/WAIT)
!WR: U1.14 (Y5), U6.16 (O2), U$1.P$13 (!WR), U$2.P$13 (!WR)
!WR_C: U1.6 (A5)
+12V: C1.+, S1.2, U12.1 (VIN), U$1.P$48 (+12V), U$2.P$48 (+12V), X1.4
-12V: C16.-, C18.2, L3.1, U$1.P$50 (-12V), U$2.P$50 (-12V)
A0: U5.11 (Y8), U6.11 (I9), U$1.P$28 (A0), U$2.P$28 (A0)
A0_C: U5.9 (A8)
A1: U5.12 (Y7), U6.10 (I8), U$1.P$27 (A1), U$2.P$27 (A1)
A1_C: U5.8 (A7)
A2: U5.13 (Y6), U6.9 (I7), U$1.P$30 (A2), U$2.P$30 (A2)
A2_C: U5.7 (A6)
A3: U5.14 (Y5), U6.8 (I6), U$1.P$29 (A3), U$2.P$29 (A3)
A3_C: U5.6 (A5)
A4: U5.15 (Y4), U6.7 (I5), U$1.P$32 (A4), U$2.P$32 (A4)
A4_C: U5.5 (A4)
A5: U5.16 (Y3), U6.6 (I4), U$1.P$31 (A5), U$2.P$31 (A5)
A5_C: U5.4 (A3)
A6: U5.17 (Y2), U6.5 (I3), U$1.P$22 (A6), U$2.P$22 (A6)
A6_C: U5.3 (A2)
A7: U5.18 (Y1), U6.4 (I2), U$1.P$21 (A7), U$2.P$21 (A7)
A7_C: U5.2 (A1)
A8: U4.11 (Y8), U$1.P$24 (A8), U$2.P$24 (A8)
A8_C: U4.9 (A8)
A9: U4.12 (Y7), U$1.P$17 (A9), U$2.P$17 (A9)
A9_C: U4.8 (A7)
A10: U4.13 (Y6), U$1.P$20 (A10), U$2.P$20 (A10)
A10_C: U4.7 (A6)
A11: U4.14 (Y5), U$1.P$19 (A11), U$2.P$19 (A11)
A11_C: U4.6 (A5)
A12: U4.15 (Y4), U$1.P$23 (A12), U$2.P$23 (A12)
A12_C: U4.5 (A4)
A13: U4.16 (Y3), U$1.P$26 (A13), U$2.P$26 (A13)
A13_C: U4.4 (A3)
A14: U4.17 (Y2), U9.14 (A), U$1.P$25 (A14), U$2.P$25 (A14)
A14_C: U4.3 (A2)
A15: U4.18 (Y1), U9.2 (B), U$1.P$18 (A15), U$2.P$18 (A15)
A15_C: U4.2 (A1)
CLK: U1.18 (Y1), U$1.P$42 (CLK), U$2.P$42 (CLK)
CLK_C: U1.2 (A1)
D0: U7.18 (B1), U8.2 (1D), U$1.P$34 (D0), U$2.P$34 (D0)
D0_C: U7.2 (A1)
D1: U7.17 (B2), U8.3 (2D), U$1.P$33 (D1), U$2.P$33 (D1)
D1_C: U7.3 (A2)
D2: U7.16 (B3), U8.4 (3D), U$1.P$36 (D2), U$2.P$36 (D2)
D2_C: U7.4 (A3)
D3: U7.15 (B4), U8.5 (4D), U$1.P$35 (D3), U$2.P$35 (D3)
D3_C: U7.5 (A4)
D4: U7.14 (B5), U8.6 (5D), U$1.P$38 (D4), U$2.P$38 (D4)
D4_C: U7.6 (A5)
D5: U7.13 (B6), U8.7 (6D), U$1.P$37 (D5), U$2.P$37 (D5)
D5_C: U7.7 (A6)
D6: U7.12 (B7), U8.8 (7D), U$1.P$40 (D6), U$2.P$40 (D6)
D6_C: U7.8 (A7)
D7: U7.11 (B8), U8.9 (8D), U$1.P$39 (D7), U$2.P$39 (D7)
D7_C: U7.9 (A8)
GND: C1.-, C2.-, C3.2, C4.2, C5.2, C6.2, C7.2, C8.2, C9.2, C10.2, C11.2, C12.2, C14.+, C16.+, C17.2, C18.1, D1.P$4, D2.A, JP2.5 (SLEEVE), L2.1, R13.1, U1.1 (G1), U1.10 (GND), U1.19 (G2), U2.1 (GAB), U2.6 (A4), U2.7 (GND), U2.13 (GBA), U3.7 (GND), U4.1 (G1), U4.10 (GND), U4.19 (G2), U5.1 (G1), U5.10 (GND), U5.19 (G2), U6.12 (GND), U7.10 (GND), U7.19 (G), U8.1 (OC), U8.10 (GND), U9.8 (GND), U10.7 (GND), U12.3 (GND), U12.5 (!ON!/OFF), U$1.P$41 (GND1), U$1.P$43 (GND2), U$2.P$41 (GND1), U$2.P$43 (GND2), X1.2, X1.3
unnamed: R2.1, U$2.P$49 (SNDIN)
unnamed: R1.1, U$1.P$49 (SNDIN)
unnamed: U8.19 (1Q), U9.6 (1C0)
unnamed: C13.+, R1.2, R2.2, R15.2, R16.2
unnamed: U8.18 (2Q), U9.10 (2C0)
unnamed: U8.17 (3Q), U9.5 (1C1)
unnamed: U8.16 (4Q), U9.11 (2C1)
unnamed: U8.15 (5Q), U9.4 (1C2)
unnamed: U8.14 (6Q), U9.12 (2C2)
unnamed: U8.13 (7Q), U9.3 (1C3)
unnamed: U8.12 (8Q), U9.13 (2C3)
unnamed: U10.2 (I1), U10.6 (O)
unnamed: U9.1 (1G), U9.15 (2G), U10.3 (O), U10.4 (I0)
unnamed: U10.8 (O), U10.12 (I0), U10.13 (I1)
unnamed: D1.P$2, S1.1 (O)
unnamed: R12.2, U11.1, U11.7, U11.8
unnamed: JP2.4 (RIGHT), R15.1
unnamed: R13.2, R14.1, U11.5
unnamed: D1.P$1, JP1.PWR
unnamed: D1.P$3, JP1.GND, JP1.GNDBREAK
unnamed: C14.-, C15.2, D3.A, L3.2, R14.2, U11.4
unnamed: C15.1, U11.3
unnamed: D3.C, L2.2, U11.2
unnamed: JP2.1 (LEFT), R16.1
unnamed: D2.C, L1.1, U12.2 (OUT)
SLOTA: U6.19 (O5), U9.7 (1Y)
SLOTB: U6.18 (O4), U9.9 (2Y)
SNDIN: C13.-
SW1_2: U$1.P$44 (SW1)
SW1_3: U$2.P$44 (SW1)
SW2_2: U$1.P$46 (SW2)
SW2_3: U$2.P$46 (SW2)
VCC: C2.+, C3.1, C4.1, C5.1, C6.1, C7.1, C8.1, C9.1, C10.1, C11.1, C12.1, C17.1, L1.2, R3.1, R4.1, R5.1, R6.2, R7.2, R8.2, R9.2, R10.2, R11.2, R12.1, U1.20 (VCC), U2.14 (VCC), U3.14 (VCC), U4.20 (VCC), U5.20 (VCC), U6.24 (VCC), U7.20 (VCC), U8.20 (VCC), U9.16 (VCC), U10.14 (VCC), U11.6, U12.4 (FB), U$1.P$45 (+5V1), U$1.P$47 (+5V2), U$2.P$45 (+5V1), U$2.P$47 (+5V2), X1.1

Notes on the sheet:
SLOTS
LOGIC
BUFFERING
POWER & FILTERING
Primary Slot Register = A8h /PPI_CS active when = A8h - ABh /SLTSL2 active when: SLOTA & /SLOTB & /MREQ & RFSH /SLTSL3 active when: SLOTA & SLOTB & /MREQ & RFSH /SLTSLEN active when: (/SLTSL2 & /RD) # (SLTSL3 & /RD) # (/IORQ & /M1) Power Circuit capable of 2A @ 5V. Bridge Rectifier may need to be u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

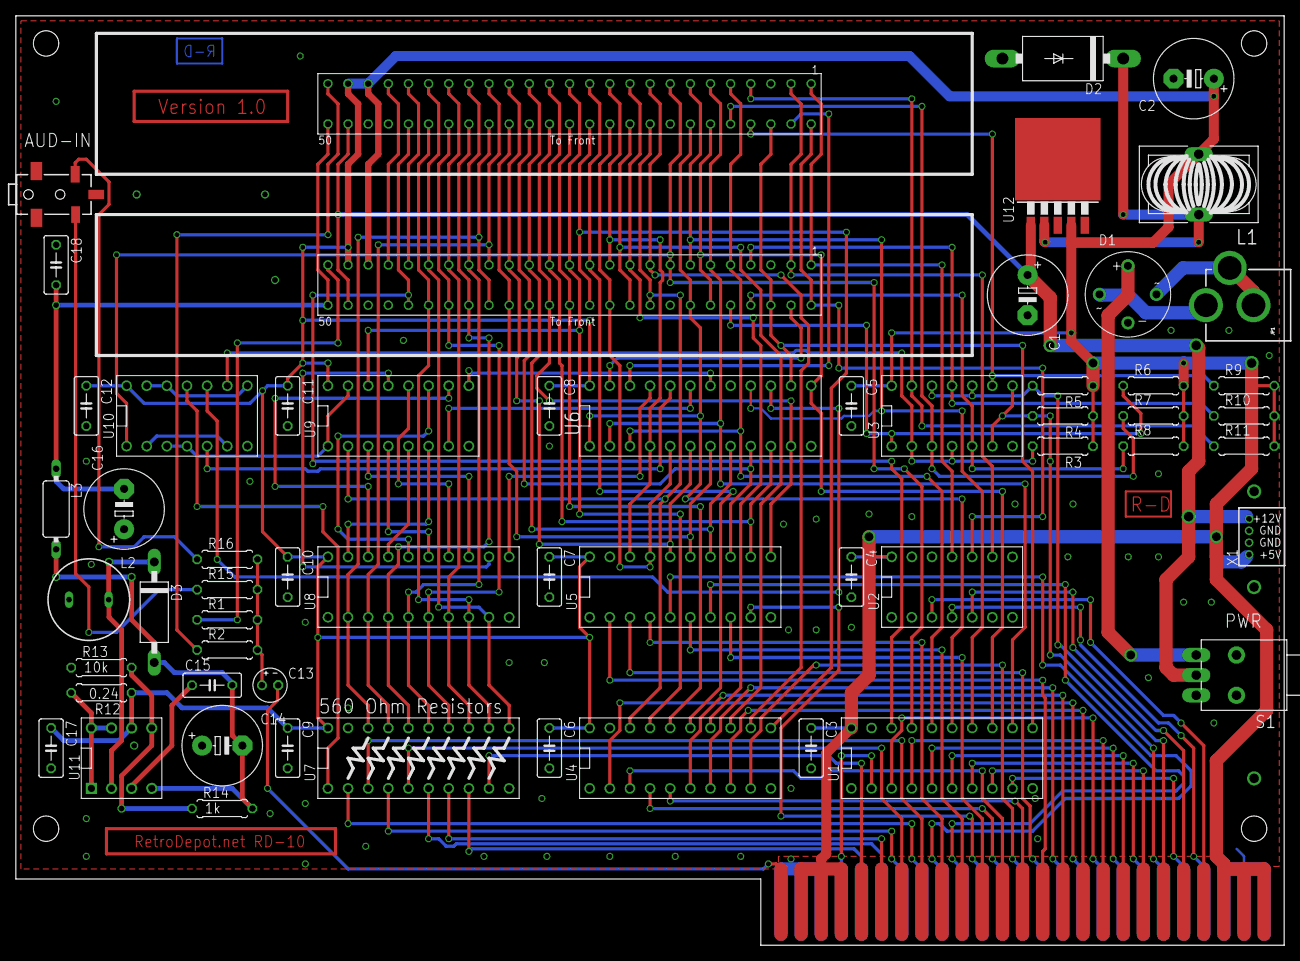
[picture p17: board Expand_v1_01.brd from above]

Board: 2 copper layers, 160.0 x 117.2 mm, 58 parts (0 on the bottom side), 81 nets.

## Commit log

2022-01-16 Initial Upload
    Upload of initial files.
    [Expand_v1_01.brd, Expand_v1_01.sch]
2022-02-23 Feb 22 Update
    Preliminary BOM, Added 3d Printable Case
    [BOM.xls, Base.stl, Feet.stl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]
2022-07-26 Add files via upload
    Added photos of completed docking station with enclosure.
2022-07-27 Update BOM.xls
    Updated BOM to reflect U7 instructions.
    [BOM.xls]
2022-08-10 Update BOM.xls
    Updated C15 Part number from 15nF capacitor to 1.5nF capacitor.
    [BOM.xls]
2022-09-08 New Versions of 3d Printable Case
    Resized cases for importation in software which expects sizes in inches.
    Added Readme file describing file versions.
    [Base_resized.stl, Feet_resized.stl, Top_resized.stl]
2022-09-09 v1.0 Rev2 PCB Added
    Added new board version, added notes, updated BOM.
    [BOM.xls, Expand_v1_02.brd, Expand_v1_02.sch]

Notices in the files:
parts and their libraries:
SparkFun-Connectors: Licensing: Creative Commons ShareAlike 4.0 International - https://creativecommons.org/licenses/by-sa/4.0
